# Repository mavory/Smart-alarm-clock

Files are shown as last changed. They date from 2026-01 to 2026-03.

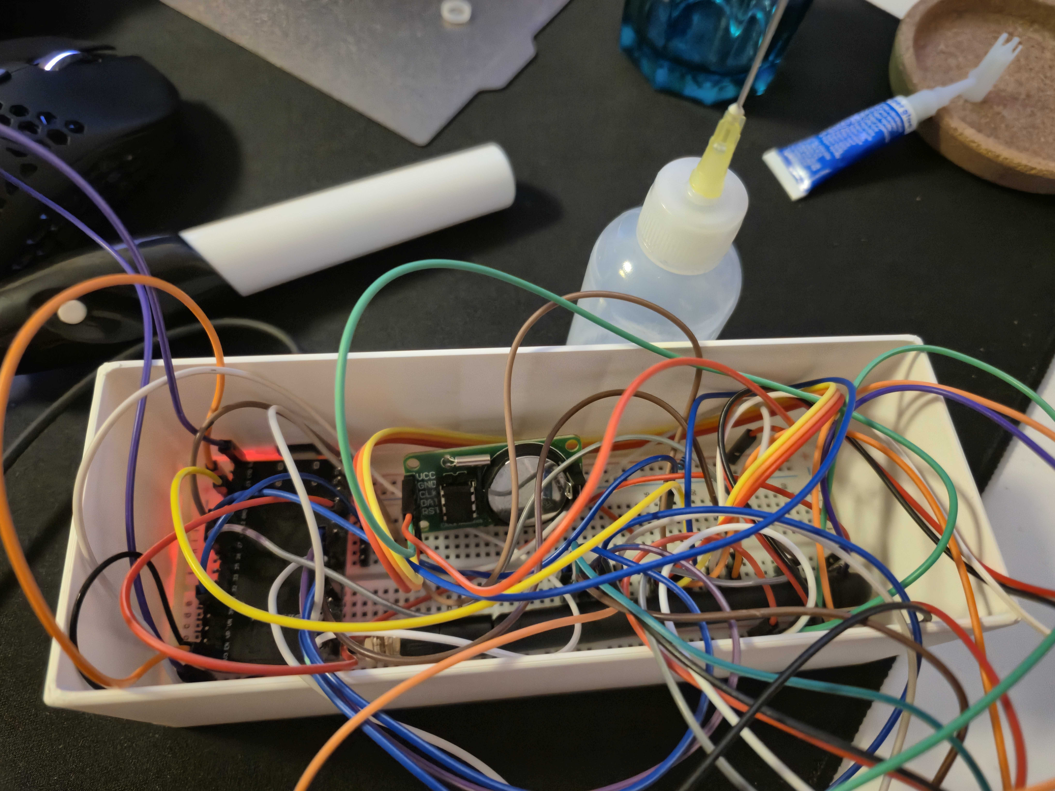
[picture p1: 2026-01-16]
Photos/20260116_223351.jpg

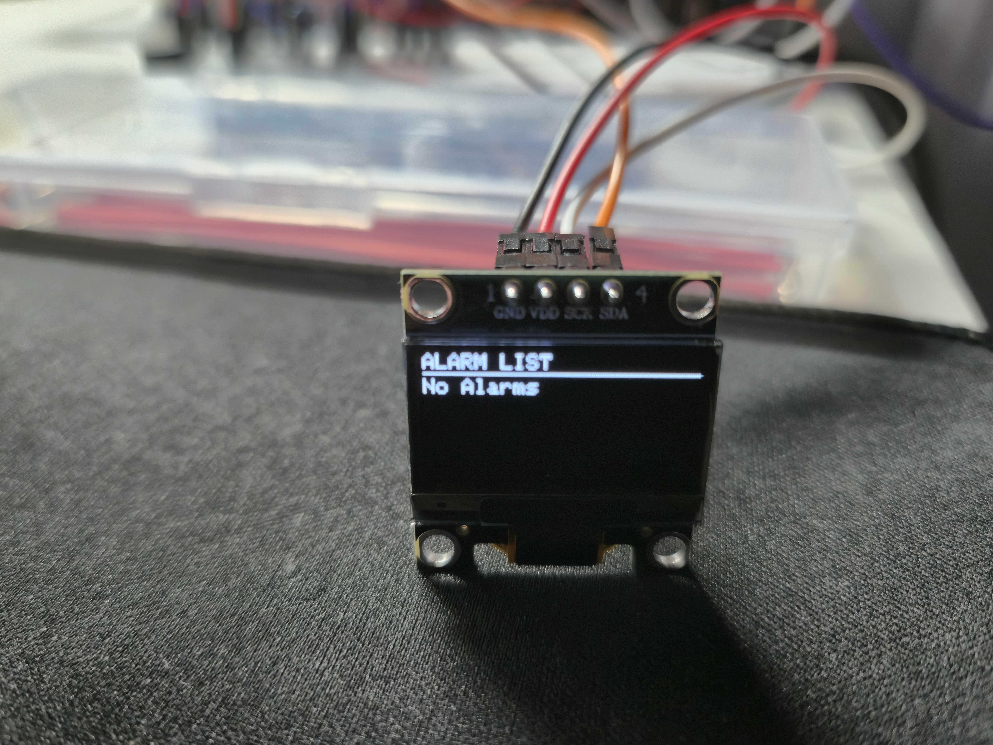
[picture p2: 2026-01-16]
Photos/20260112_203040.jpg

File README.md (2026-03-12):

# Smart Alarm Clock (SAC)

Using ESP32 you can have your own alarm clock that is controllable via the web!

## Why did I do this?

I was always late or needed some encouragement! So I created SAC, which is web-controlled and very compact and minimalist. Now I can adjust my alarm clock via the web on my PC while I'm in the kitchen (for example).

## Features

- Web interface
- You can edit alarms via the web
- You see diagnostics on the display
- Day/night mode

## Scripts

It's the only script you need and it's about 460 lines long! It contains everything from libraries to the website. 
Just edit the WiFi and password on line 237 and you can upload it straight to the ESP32 and everything should work.

### Home page:


## How it works?

On the website you choose what you need, for example, you create a one-day alarm clock with vibration and buzzer for 21:30. At 21:30 your alarm will start and you can turn it off using the button on the website or via the button directly on the alarm clock.
Also, if you press the button twice, you will see all current alarms on the display and if you hold the button, you will get to the diagnostics, where you can see all important information!

### Libraries:

```
- Arduino.h
- WiFi.h
- ESPAsyncWebServer.h 
- AsyncTCP.h
- Adafruit_NeoPixel.h
- LittleFS.h
- SD.h
- SPI.h
- Wire.h
- Adafruit_GFX.h
- Adafruit_SSD1306.h
- RtcDS1302.h
- ThreeWire.h
- OneButton.h
- time.h
```

## 3D models

https://www.tinkercad.com/things/f3PBRpHUPhY-clock?sharecode=p_ixkk5DhO9dDXulNEwirXyC8I3PMVLbobYcKOfEwlo

Here is a view of the top and bottom of the case:





## Wiring Diagram



## BOM (Bill of Materials)

| Item | Quantity | Price | Link |
|---|---|---|---|
| ESP32 | 1 | $5.43 | [Buy](https://www.aliexpress.com/item/1005009694232832.html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) |
| OLED display | 1 | $1.44 | [Buy](https://www.aliexpress.com/item/32896971385.html?spm=a2g0o.order_list.order_list_main.73.59371802jT2w75) |
| SD card module | 1 | $0.56 | [Buy](https://www.aliexpress.com/item/1005009113598175.html?spm=a2g0o.order_list.order_list_main.48.59371802jT2w75) |
| Breadboard | 1 | $2.56 | [Buy](https://www.aliexpress.com/item/1005009799908389.html) |
| Vibration motor | 1 | $0.8 | [Buy](https://www.aliexpress.com/item/1005005518779084.html?spm=a2g0o.order_list.order_list_main.84.59371802jT2w75) |
| Buzzer | 1 | $1.28 | [Buy](https://www.aliexpress.com/item/1005006260328559.html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) |
| Jumpers | Much | $4.73 | [Buy](https://www.aliexpress.com/item/1005002611994443.html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) |
| Button | 1 | $.2.02 | [Buy](https://www.aliexpress.com/item/1005007197228321.html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) |
| RTC modul | 1 | $1.78 | [Buy](https://www.aliexpress.com/item/1005006627321251.html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) |
| Shipping to CZ | / | $3.96 | / |

## There is the final video of how it works!!

_Here is a youtube video where you can see how it works:_ [Link](https://youtu.be/AV3PfRDRrco)



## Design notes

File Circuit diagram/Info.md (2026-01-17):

# Wiring Diagram 

### Inputs:
- **Button:**
  - SIG: GPIO 4
  - VCC: 5V 
  - GND: GND
- **LDR Photosensor:**
  - SIG: GPIO 34
  - Circuit: 3.3V --- LDR --- GPIO 34 --- 10k resistor --- GND

### Outputs:
- **Vibration Motor Module:**
  - SIG: GPIO 26
  - VCC: 5V
  - GND: GND
- **Buzzer Module:**
  - SIG: GPIO 33
  - GND: GND

### Display & Storage:
- **OLED Display:**
  - SDA: GPIO 21
  - SCL: GPIO 22
  - VCC: 5V
  - GND: GND
- **MicroSD Card Module (SPI):**
  - CS: GPIO 5
  - MOSI: GPIO 23
  - MISO: GPIO 19
  - SCK: GPIO 18
  - VCC: 5V
  - GND: GND

### Real Time Clock:
- **RTC DS1302 (3-Wire):**
  - DAT (I/O): GPIO 14
  - CLK (SCLK): GPIO 13
  - RST (CE): GPIO 27
  - VCC: 3.3V
  - GND: GND

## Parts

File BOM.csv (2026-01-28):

Item | Quantity | Price | Link
ESP32 | 1 | $5.43 | https://www.aliexpress.com/item/1005009694232832.html?curPageLogUid=bPYYmnweQOZ8
OLED display | 1 | $1.44 | https://www.aliexpress.com/item/32896971385.html
SD card module | 1 | $0.56 | https://www.aliexpress.com/item/1005009113598175.html
Breadboard | 1 | $2.56 | https://www.aliexpress.com/item/1005009799908389.html
Vibration motor | 1 | $0.8 | https://www.aliexpress.com/item/1005005518779084.html
Buzzer | 1 | $1.28 | https://www.aliexpress.com/item/1005006260328559.html?curPageLogUid=u9zf8d5xh8uM
Jumpers | Much | $4.73 | https://www.aliexpress.com/item/1005002611994443.html?curPageLogUid=fx2zB0EGcu5H
Button | 1 | $.2.02 | https://www.aliexpress.com/item/1005007197228321.html?curPageLogUid=niWf4yREvIVl
RTC modul | 1 | $1.78 | https://www.aliexpress.com/item/1005006627321251.html?curPageLogUid=19tjyUq9NzO2
Shipping to CZ | / | $3.96 | /

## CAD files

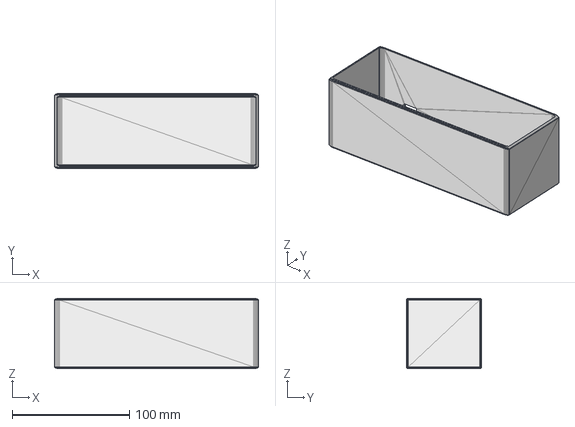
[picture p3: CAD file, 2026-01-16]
CAD/Bottom.step
174.0 x 64.0 x 60.0 mm

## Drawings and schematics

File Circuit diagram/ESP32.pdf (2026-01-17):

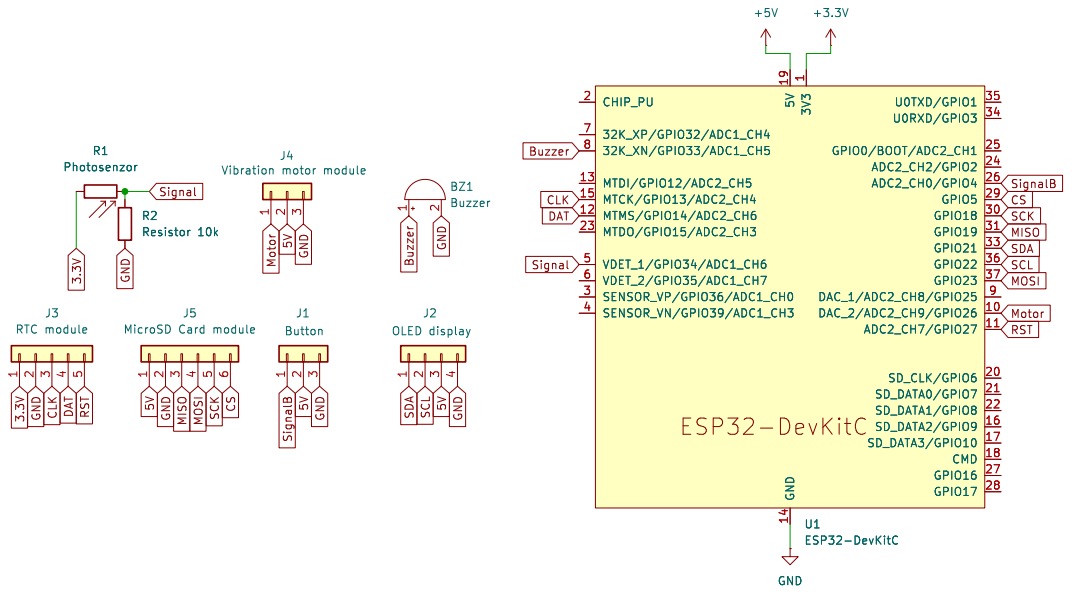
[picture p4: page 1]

1 U0TXD/GPIO1 35 U0RXD/GPIO3 34 GPIO0/BOOT/ADC2_CH1 25 ADC2_CH2/GPIO2 24 ADC2_CH0/GPIO4 26 GPIO5 29 GPIO18 30 GPIO19 31 GPIO21 33 GPIO22 36 GPIO23 37 DAC_1/ADC2_CH8/GPIO25 9 DAC_2/ADC2_CH9/GPIO26 10 ADC2_CH7/GPIO27 11 SD_CLK/GPIO6 20 SD_DATA0/GPIO7 21 SD_DATA1/GPIO8 22 SD_DATA2/GPIO9 16 SD_DATA3/GPIO10 17 CMD 18 GPIO16 27 GPIO17 28 U1ESP32-DevKitC GND

Id: 1/1 Title: Smart Alarm Clock (SAC) File: ESP32.kicad_sch Sheet: /

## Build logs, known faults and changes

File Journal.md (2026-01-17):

<!--
  This journal is auto generated by Hack Club Blueprint.
-->

## 1/10/2026 12 PM - The beginning of my project!!  

_Time spent: 1.2h_  

I was thinking about what to create and suddenly it occurred to me that I could create a **SMART ALARM CLOCK**! It would have: 
- ESP32
- RTC Module
- OLED display (128x64)
- Passive buzzer
- Photosensor
- Vibration motor
- Button
- MicroSD card adapter
- Speaker

**Everything would work via the web**, where sounds could be recorded, e.g. **buzzer**, **vib. motor** and so on could be turned off. 
Also, the clock would always connect to WiFi at **3:00 local time** and adjust the time!

  

## 1/10/2026 10:40 PM - Connecting the components :)  

_Time spent: 0.9h_  

At first I was wondering if I should use a **smaller breadboard** or a **bigger one. I decided to go for the bigger one so that I wouldn't get lost later.**
First I started connecting the cables to the components and later I connected them to the breadboard, unfortunately I don't have **female to female**, so I had to use the _2x more cables method again_... 



## 1/10/2026 10:46 PM - Component testing!  

_Time spent: 0.7h_  

When I had it connected, I started testing each thing **one by one on short codes**, because I hadn't worked with a few things yet. **At first**, the display didn't work, so I wondered why...
After a while, I found out that it was the code, so I was relieved and I thought about whether I should still use the **breadboard power supply**, but I decided not to use it. When I had everything ready and tested, I moved on to soldering.

Snímek obrazovky 2026-01-10 224529

## 1/10/2026 10:52 PM - Soldering   

_Time spent: 1.4h_  

Since I had just bought **an amplifier and a speaker**, I had to connect them somehow first. I thought I would do it easily - I would use a pin strip, but it wasn't that easy. **The holes were too close together**, so I thought I could put it in a **breadboard** and it wasn't...
So I decided to solder it with wires. I first prepared the wires for powering the amplifier itself and when I had them, **I also soldered the speaker**.



## 1/10/2026 11:07 PM - Start of coding  

_Time spent: 1.2h_  

After **successful soldering**, I quickly moved on to writing the code. I had never written any code before and I was wondering **how I would make the speaker work** and everything together.
At first, I came up with the code when I would not use the speaker yet and later I would put it there. I was more confused about the **functionality of the MicroSD card** module, which always blubbed 💀 - today too... When I uploaded the code, writing to the card did not work for me and I also did not know why, **the website did not work.**


## 1/10/2026 11:36 PM - MicroSD card works!  

_Time spent: 0.7h_  

When my **SD card** didn't work, I decided to put it in my computer again and suddenly it showed nothing, I formatted the card, I don't know why... So I put it on **FAT32** so that the ESP32 could read it and upload the files important for the next code there.
I started to redo the **errors** in my code that had been bothering me so far and I made a function to always tell me if the SD card was fine.
I connected everything and it worked, the **website didn't look very nice**, but I didn't bother with that yet, because I knew that more important things were waiting for me.



## 1/10/2026 11:53 PM - Continuing coding  

_Time spent: 1.2h_  

I thought everything would go quickly, but as soon as **I started coding**, I was looking for a library that would be good for Bluetooth, I couldn't find the one I wanted, but after some time I found it: _BluetoothA2DPSink.h_. 
It worked well and I was able to connect my phone to the **ESP32**, but I had one big problem... The antenna can only handle **Bluetooth or WiFi**, so I came up with a brilliant solution that when Bluetooth is turned on, WiFi stays in "standby mode" and waits. 
**Everything worked** and I was able to connect the speaker later.


## 1/11/2026 11 AM - ONE BIG MISTAKE  

_Time spent: 2.1h_  

When I had the code ready, I could move on to connecting the **Speaker to the ESP32**, I added another **10uF** capacitor there to cover the noise, I also connected a **100uF** to the power supply... So when I changed the code and uploaded it to the **ESP32**, unfortunately it didn't work at first, I don't know why, it just made noise.
I tried editing the code, **playing music** only on the bits that the ESP32 reads,.. and nothing. So I spent a lot of time just testing if it works and probably doesn't work. So **I removed it** from the whole project.



## 1/11/2026 4 PM - Rewriting the code but without the speaker  

_Time spent: 1.5h_  

When I recovered from everything, I started to redo the code so that it **would work** even without a speaker. **I redid all the pins** to make it as easy as possible and started coding. I had to start all over again...
The **website was completely redesigned** into a space theme, but I might change it. I was more bothered by the fact that the _ArduinoJSON_ library didn't work for me, so after about an hour **I immediately put it away** and continued without it.



## 1/12/2026 7 PM - Web interface  

_Time spent: 2.1h_  

After a few hours I finished the **web interface**. I completely redesigned it because it looked like **space** at first and wasn't black and white - **Now it's modern** and minimalist with elements and buttons to control the **alarm clock**!

### Here is an older version:


### Here is the new modern version!!


**In the new version there are:**
- buttons for testing the vibration motor, turning off the OLED, adding a new alarm (you can choose if you want a buzzer or a vibration motor)
- I can also see how much space is left on the SD card
- I can see the temperature of the ESP32  

## 1/12/2026 8 PM - The code is done!!   

_Time spent: 1.3h_  

After the website was finished, sjem started to redo the code to make it modern and have all the features!

### Home screen:
- You can see the date
- You can see the exact time
- Signaling if you are connected to WiFi
- Day mode or night mode


### Diagnostics:
- IP address
- RAM
- How long the system has been running
- How many times has the alarm been set


### Alarm page:
- You can see all your set alarms


## 1/16/2026 6 PM - Making a 3D case!!  

_Time spent: 0.9h_  

After **finishing the code**, I started working on the **3D case**, which is very important to print well. I do everything in **Tinkercad**, because I find it to be the lightest and _free program_ running on the web, so **I liked it** a while ago.
At first, I started making the bottom part, which has dimensions of **174x64** (_the walls have a size of +- **2mm**_). When I had the bottom part, I later moved to the **top part**, which will be heavier, mainly because of the **components that will be there**.

### Bottom part:



## 1/16/2026 7:29 PM - Printing and measuring  

_Time spent: 0.6h_  

In the meantime, I started measuring **all the components** that I would place on the top.
I started with the **OLED display** and gradually continued with the **photosensor**, **button**,....
The hardest part was probably **figuring out the right dimensions** for the displays so that everything **would fit and work**.



## 1/16/2026 7:45 PM - Making a top cover for a 3D case  

_Time spent: 1.1h_  

Right after **measuring**, sjem moved back to TinkerCad and continued **modeling the top cover**, which was important to make as accurate as possible.
I placed holes on the top for the **OLED**, **buzzer**, **photosensor**, and **button**.
Everything has a little gap, so everything should fit well!
(_I also created a **3D model** of the button that will be glued to the switch_)

### Overall view of the 3D model:


### Top view:

_Hopefully everything will work out and I will be able to move on!_  

## 1/16/2026 9 PM - Code editing!  

_Time spent: 0.7h_  

While I was waiting for the upper part of the **3D case**, I decided to finish the code to make it more stable.
I also **edited the labels** to make it a little easier to understand. Before, the photosensor didn't work very well for me, sometimes after a reset the **ESP32** worked and sometimes it took a break... So I rewrote some more and it works _beautifully_!


## 1/16/2026 10:36 PM - Cosmetic treatment for 3D case  

_Time spent: 0.5h_  

After printing everything, I prepared things for gluing, editing, etc. **3D case**.
**At the beginning**, I also prepared a buzzer and a photosensor to connect to the jumpers so that they could be inserted into the case! I also **adjusted the cables** so that everything fit well and something didn't fall out right away...
Next, I took a knife and **cut off the edges** that were sticking out and generally sanded the surface of the 3D case a little!


## 1/16/2026 10:48 PM - Placing things in the top of the 3D case  

_Time spent: 1.5h_  

When I **finished the cosmetic adjustments**, I moved on to putting things in the top of the **3D case**!
- First I started with the **buzzer**, which held there beautifully and didn't need glue.
- Then I added a button that needed a **very small amount of glue** so that it wouldn't fall off when I pressed it...
- I also put a **photosensor** in the hole, but that one went worse - the hole was about 1mm too small (_even though I measured it correctly, so there's still a gap there_), but then I put it in there and connected the wires.
- Last I put the **OLED in the top**, which I didn't want to glue, so I decided to stick it with **electrical tape** and everything worked beautifully!

_So when I had everything ready, I had to wait for a while for **everything to dry** and in the meantime I did a few things in **KiCad** (but that's a later topic)_

20260116_224936 (1)

## 1/16/2026 11 PM - The case is finally closed!  

_Time spent: 1.2h_  

After a long time, **I finally finished the case**!
Everything works very well and so sjem decided to **glue the upper part** to the lower one - but it wasn't that easy.
First I had to bend the cables to the **photosensor and buzzer** so that the jumpers wouldn't fall out, and even then it happened a few times, so it took me a while.
I also had to rewire the buzzer on the **breadboard** a little, but everything else is great! When I had it, **I finished the last things** and closed it (_I just stretched it with tape to test it..._)
Everything worked, but suddenly the **buzzer didn't work** on the second try, so **I wondered why**, but when **I opened the case**, a wire just fell out, so I said, goooood.
So when I made the **4th try**, everything worked beautifully and I was happy. So I closed the case with glue and could continue with the **circuit diagram**!!

### Cable connection:


### Closed case:


## 1/17/2026 3:28 PM - Circuit diagram  

_Time spent: 1.5h_  

When I finished the overall wiring and the **3D case**, I started making a circuit diagram in KiCad.
It took me quite a while because I had been doing it for a long time, but then **I remembered** how to **do some things**.
I gradually added various devices and connected them to the **ESP32**. The photosensor was probably the most difficult for me because I couldn't find the exact module for it, but after some time I found it. Later I added a **10K resistor** to it and slowly everything was done.


## 1/17/2026 3:38 PM - Circuit diagram is finished!  

_Time spent: 0.8h_  

So when I had everything ready, I started connecting things to the **ESP32**.
At first **I had to look at the code** because I couldn't remember the pins where the **components** were connected, but as I got closer to the end, I started to remember...
After about **0.8 hours** I had everything finished and I rendered it all and **uploaded it** straight to **GitHub**!
Snímek obrazovky 2026-01-17 152935
_Here is the link to download the PDF:_ [ESP32](/user-attachments/blobs/proxy/eyJfcmFpbHMiOnsiZGF0YSI6ODQ0MjEsInB1ciI6ImJsb2JfaWQifX0=--f22b4212b44062768d9ba6f794fccc316fd4df73/ESP32.pdf)  

## 1/17/2026 4 PM - GitHub editing  

_Time spent: 1.3h_  

When I was done, I started editing the **GitHub repo**. I exported everything one by one and later **uploaded everything** to the aforementioned repo.
It took me about half an hour in total, because I always have to convert **.STL** to **.STEP** and also always find out where **my schematic** is saved...

Later, I started writing **README.md**, **Journal.md**, **Info.md**... That probably took me the most time, because it was quite difficult and then I had to edit it a f**ew times anyway**. When I had it, I saved everything **and made a video** of how everything works.


## 1/17/2026 5 PM - SMART ALARM CLOCK IS DONE!!  

_Time spent: 1.8h_  

Using ESP32 you can have your own alarm clock that is controllable via the web!

## Why did I do this?

I was always late or needed some encouragement! So I created SAC, which is web-controlled and very compact and minimalist. Now I can adjust my alarm clock via the web on my PC while I'm in the kitchen (for example).

## Features

- Web interface
- You can edit alarms via the web
- You see diagnostics on the display
- Day/night mode

## Scripts

It's the only script you need and it's about 460 lines long! It contains everything from libraries to the website. 
Just edit the WiFi and password on line 237 and you can upload it straight to the ESP32 and everything should work.

### Home page:


## How it works?

On the website you choose what you need, for example, you create a one-day alarm clock with vibration and buzzer for 21:30. At 21:30 your alarm will start and you can turn it off using the button on the website or via the button directly on the alarm clock.
Also, if you press the button twice, you will see all current alarms on the display and if you hold the button, you will get to the diagnostics, where you can see all important information!

### Libraries:

```
- Arduino.h
- WiFi.h
- ESPAsyncWebServer.h 
- AsyncTCP.h
- Adafruit_NeoPixel.h
- LittleFS.h
- SD.h
- SPI.h
- Wire.h
- Adafruit_GFX.h
- Adafruit_SSD1306.h
- RtcDS1302.h
- ThreeWire.h
- OneButton.h
- time.h
```

## 3D models

Here is a view of the top and bottom of the case:





## Wiring Diagram



## There is the final video of how it works!!

_Here is a youtube video where you can see how it works:_ [Link](https://youtu.be/AV3PfRDRrco)



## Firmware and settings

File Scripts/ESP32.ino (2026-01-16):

#include <WiFi.h>
#include <ESPAsyncWebServer.h>
#include <SD.h>
#include <SPI.h>
#include <Wire.h>
#include <Adafruit_GFX.h>
#include <Adafruit_SSD1306.h>
#include <RtcDS1302.h>
#include <ThreeWire.h>
#include <OneButton.h>
#include "time.h"

//PINOUT
#define PIN_SD_CS    5
#define PIN_BUZZER   33
#define PIN_VIBRO    26   //zde je ten pin pro motor
#define PIN_BTN      4
#define PIN_LDR      34
#define OLED_SDA     21
#define OLED_SCL     22

ThreeWire myWire(14, 13, 27); // DAT, CLK, RST!!!!!
RtcDS1302<ThreeWire> Rtc(myWire);
Adafruit_SSD1306 display(128, 64, &Wire, -1);
AsyncWebServer server(80);
OneButton button(PIN_BTN, true);

bool isAlarmActive = false;
bool oledPower = true;
String globalIP = "0.0.0.0";
unsigned long lastUpdate = 0;
unsigned long stateTimer = 0;
unsigned long bootTime = 0;

enum State { CLOCK, LIST, DIAG };
State displayState = CLOCK;

// Alarm settingues
int actBuzzer = 1;
int actVibro = 1;
int actFreq = 1500;

const char* ntpServer = "pool.ntp.org";
const long  gmtOffset_sec = 3600;     //pro mě to ej gmt+1
const int   daylightOffset_sec = 3600; // letní čas

// esp32 čip teplota
#ifdef __cplusplus
extern "C" { uint8_t temprature_sens_read(); }
#endif

// logika tlacitka
void handleClick() {
  if (isAlarmActive) {
    // stop alarmu
    isAlarmActive = false;
    noTone(PIN_BUZZER);
    digitalWrite(PIN_VIBRO, LOW);
  } else {
    if (!oledPower) {
      oledPower = true;
    } else {
      displayState = CLOCK;
    }
  }
}

void handleDoubleClick() {
  if(!isAlarmActive) { displayState = LIST; stateTimer = millis(); }
}

void handleLongPress() {
  if(!isAlarmActive) { displayState = DIAG; stateTimer = millis(); }
}

void runVibrationEffect() {
  unsigned long m = millis();
  if (actVibro == 1) { 
    // konstanta
    digitalWrite(PIN_VIBRO, HIGH); 
  } 
  else if (actVibro == 2) { 
    int p = m % 1000;
    if ((p > 0 && p < 150) || (p > 250 && p < 400)) digitalWrite(PIN_VIBRO, HIGH);
    else digitalWrite(PIN_VIBRO, LOW);
  }
}

// web, jako vzdy hrozne
const char index_html[] PROGMEM = R"rawliteral(
<!DOCTYPE html>
<html lang="en">
<head>
<meta charset="UTF-8">
<meta name="viewport" content="width=device-width, initial-scale=1">
<title>VORY OS V5</title>
<style>
  :root { --bg: #ffffff; --text: #000000; --acc: #000000; }
  body { background: var(--bg); color: var(--text); font-family: -apple-system, BlinkMacSystemFont, "Segoe UI", Roboto, sans-serif; margin: 0; padding: 20px; max-width: 600px; margin: auto; }
  h1 { border-bottom: 4px solid var(--text); padding-bottom: 10px; letter-spacing: -1px; text-transform: uppercase; }
  .card { border: 2px solid #eee; padding: 20px; border-radius: 12px; margin-bottom: 20px; box-shadow: 0 4px 10px rgba(0,0,0,0.05); }
  label { font-size: 10px; font-weight: 800; text-transform: uppercase; color: #888; display: block; margin-bottom: 8px; }
  .grid { display: grid; grid-template-columns: 1fr 1fr; gap: 15px; }
  input, select, button { width: 100%; box-sizing: border-box; padding: 12px; border: 2px solid #ddd; border-radius: 8px; font-size: 14px; font-weight: 600; background: #fff; appearance: none; }
  input:focus, select:focus { border-color: #000; outline: none; }
  button { background: #000; color: #fff; border-color: #000; cursor: pointer; transition: 0.2s; }
  button:hover { background: #333; transform: translateY(-2px); }
  button.danger { background: #ff3b30; border-color: #ff3b30; }
  button.danger:hover { background: #d63026; }
  .alarm-item { display: flex; justify-content: space-between; align-items: center; padding: 15px 0; border-bottom: 1px solid #eee; }
  .tag { font-size: 10px; background: #eee; padding: 4px 8px; border-radius: 4px; margin-left: 5px; }
  #status-dot { height: 10px; width: 10px; background-color: #ccc; border-radius: 50%; display: inline-block; margin-right: 5px; }
  .online { background-color: #34c759 !important; }
</style>
<script>
  function el(id){ return document.getElementById(id); }
  function toggleDate(v){ el('date_box').style.display = (v==='once') ? 'block' : 'none'; }
  
  function loadData() {
    fetch('/api/list').then(r=>r.text()).then(h => el('alarm-list').innerHTML = h);
    fetch('/api/status').then(r=>r.json()).then(j => {
      el('sys-status').innerText = j.status;
      el('sys-temp').innerText = j.temp + "°C";
      el('sd-usage').innerText = j.sd;
      el('status-dot').className = (j.online ? 'online' : '');
    });
  }
  
  function sendCmd(cmd) { fetch('/cmd?do='+cmd).then(()=>loadData()); }
  
  function addAlarm() {
    let t = el('t').value, m = el('m').value;
    let d = (m === 'daily') ? 'daily' : el('d_val').value;
    let b = el('b').value, v = el('v').value, f = el('f').value;
    if(!t) return alert("Please set time!");
    
    fetch(`/api/add?t=${t}&d=${d}&b=${b}&v=${v}&f=${f}`).then(() => {
      el('t').value = '';
      loadData();
    });
  }
  
  function delAlarm(id) {
    if(confirm("Delete this alarm?")) {
      fetch(`/api/del?id=${id}`).then(()=>loadData());
    }
  }

  setInterval(loadData, 2000);
</script>
</head>
<body onload="loadData()">
  <h1>VORY OS <span style="font-size:12px; vertical-align:middle; background:#000; color:#fff; padding:2px 6px; border-radius:4px;">PRO</span></h1>
  
  <div class="card">
    <div style="display:flex; justify-content:space-between;">
      <div><span id="status-dot"></span><span id="sys-status">LOADING...</span></div>
      <div id="sys-temp">--°C</div>
    </div>
    <div style="margin-top:10px; font-size:12px; color:#666;">SD Storage: <span id="sd-usage">--</span></div>
  </div>

  <div class="card">
    <label>Control Center</label>
    <div class="grid">
      <button onclick="sendCmd('oled')">Toggle OLED</button>
      <button onclick="sendCmd('ntp')">NTP Sync (Net)</button>
      <button onclick="sendCmd('test_vib')">Test Motor</button>
      <button class="danger" onclick="sendCmd('kill')">STOP ALARM</button>
    </div>
  </div>

  <div class="card">
    <label>New Alarm</label>
    <div class="grid">
      <input type="time" id="t">
      <select id="m" onchange="toggleDate(this.value)">
        <option value="daily">Repeat Daily</option>
        <option value="once">One-time (Date)</option>
      </select>
    </div>
    <div id="date_box" style="display:none; margin-bottom:10px;">
      <input type="date" id="d_val">
    </div>
    <div class="grid">
      <select id="b"><option value="1">Buzzer: Loud</option><option value="2">Buzzer: Pulse</option><option value="0">Silent</option></select>
      <select id="v"><option value="1">Vibro: Constant</option><option value="2">Vibro: Heartbeat</option><option value="0">Off</option></select>
    </div>
    <input type="number" id="f" value="1500" placeholder="Hz (Pitch)">
    <button onclick="addAlarm()" style="margin-top:10px;">SAVE ALARM</button>
  </div>

  <div class="card">
    <label>Active Alarms</label>
    <div id="alarm-list">Loading...</div>
  </div>
</body>
</html>
)rawliteral";

// seťup
void setup() {
  Serial.begin(115200);
  bootTime = millis();
  
  pinMode(PIN_VIBRO, OUTPUT);
  pinMode(PIN_BUZZER, OUTPUT);
  pinMode(PIN_LDR, INPUT);
  
  // test motoru
  digitalWrite(PIN_VIBRO, HIGH); delay(200); digitalWrite(PIN_VIBRO, LOW);

  Wire.begin(OLED_SDA, OLED_SCL);
  display.begin(SSD1306_SWITCHCAPVCC, 0x3C);
  
  // booting animacia
  display.clearDisplay();
  display.setTextSize(1); display.setTextColor(WHITE);
  display.setCursor(30, 20); display.println("VORY OS V5");
  display.drawRect(14, 40, 100, 10, WHITE);
  for(int i=0; i<100; i+=10) {
    display.fillRect(16, 42, i, 6, WHITE);
    display.display();
    delay(50);
  }

  button.setClickTicks(200);
  button.setPressTicks(2000);
  button.attachClick(handleClick);
  button.attachDoubleClick(handleDoubleClick);
  button.attachLongPressStart(handleLongPress);

  Rtc.Begin();
  if (!SD.begin(PIN_SD_CS)) { Serial.println("SD Fail"); }

  // WiFi
  WiFi.begin("Vory", "Pazout2604"); // CHANGE PASSWORD
  int attempt = 0;
  while (WiFi.status() != WL_CONNECTED && attempt < 10) { delay(500); attempt++; }
  if(WiFi.status() == WL_CONNECTED) globalIP = WiFi.localIP().toString();
  
  configTime(gmtOffset_sec, daylightOffset_sec, ntpServer);

  server.on("/", HTTP_GET, [](AsyncWebServerRequest *r){ r->send(200, "text/html", index_html); });
  
  server.on("/api/status", HTTP_GET, [](AsyncWebServerRequest *r){
    String json = "{";
    json += "\"status\":\"" + String(isAlarmActive ? "ALARM ACTIVE" : "SYSTEM READY") + "\",";
    json += "\"temp\":\"" + String((temprature_sens_read() - 32) / 1.8, 1) + "\",";
    json += "\"online\":" + String(WiFi.status() == WL_CONNECTED ? "true" : "false") + ",";
    json += "\"sd\":\"" + String(SD.totalBytes() / (1024*1024)) + " MB\"";
    json += "}";
    r->send(200, "application/json", json);
  });

  server.on("/cmd", HTTP_GET, [](AsyncWebServerRequest *r){
    String cmd = r->getParam("do")->value();
    if(cmd == "oled") oledPower = !oledPower;
    else if(cmd == "kill") { isAlarmActive = false; noTone(PIN_BUZZER); digitalWrite(PIN_VIBRO, LOW); }
    else if(cmd == "test_vib") { 
      digitalWrite(PIN_VIBRO, HIGH); delay(1000); digitalWrite(PIN_VIBRO, LOW); 
    }
    else if(cmd == "ntp") {
      struct tm timeinfo;
      if(getLocalTime(&timeinfo)){
        RtcDateTime now(timeinfo.tm_year + 1900, timeinfo.tm_mon + 1, timeinfo.tm_mday, timeinfo.tm_hour, timeinfo.tm_min, timeinfo.tm_sec);
        Rtc.SetDateTime(now);
      }
    }
    r->send(200);
  });

  server.on("/api/list", HTTP_GET, [](AsyncWebServerRequest *r){
    File f = SD.open("/alarms.txt", FILE_READ);
    String html = ""; int id = 0;
    if(!f){ r->send(200, "text/plain", "SD Error"); return; }
    
    while(f.available()){
      String l = f.readStringUntil('\n');
      if(l.length() > 5) {
        int s1 = l.indexOf('|'); int s2 = l.indexOf('|', s1+1);
        String t = l.substring(0, s1); 
        String d = l.substring(s1+1, s2);
        if(d != "daily") { 
            // Format 2026-01-12 -> 12.01.
            d = d.substring(8,10) + "." + d.substring(5,7) + "."; 
        } else {
            d = "Daily";
        }
        
        html += "<div class='alarm-item'>";
        html += "<div><span style='font-size:18px; font-weight:bold'>" + t + "</span> <span class='tag'>" + d + "</span></div>";
        html += "<button class='danger' style='width:auto; padding:5px 10px; font-size:12px' onclick='delAlarm("+String(id)+")'>DEL</button>";
        html += "</div>";
        id++;
      }
    }
    f.close();
    r->send(200, "text/html", html.length() > 0 ? html : "No Alarms Set");
  });

  server.on("/api/add", HTTP_GET, [](AsyncWebServerRequest *r){
    String row = r->getParam("t")->value() + "|" + r->getParam("d")->value() + "|" + r->getParam("b")->value() + "|" + r->getParam("v")->value() + "|" + r->getParam("f")->value();
    File f = SD.open("/alarms.txt", FILE_APPEND); f.println(row); f.close();
    r->send(200);
  });

  server.on("/api/del", HTTP_GET, [](AsyncWebServerRequest *r){
    int id = r->getParam("id")->value().toInt();
    File f = SD.open("/alarms.txt", FILE_READ);
    String content = ""; int cnt = 0;
    while(f.available()){
      String l = f.readStringUntil('\n');
      if(cnt != id && l.length() > 0) content += l + "\n";
      cnt++;
    }
    f.close();
    SD.remove("/alarms.txt"); // Clean delete
    File fw = SD.open("/alarms.txt", FILE_WRITE);
    fw.print(content);
    fw.close();
    r->send(200);
  });

  server.begin();
}

// loopppp
void loop() {
  button.tick();
  
  if(displayState != CLOCK && millis() - stateTimer > 10000) displayState = CLOCK;

  RtcDateTime now = Rtc.GetDateTime();

  if (now.Second() == 0 && !isAlarmActive) {
    File f = SD.open("/alarms.txt", FILE_READ);
    char curT[6], curD[11];
    sprintf(curT, "%02d:%02d", now.Hour(), now.Minute());
    sprintf(curD, "%04d-%02d-%02d", now.Year(), now.Month(), now.Day());
    
    while(f.available()){
      String l = f.readStringUntil('\n');
      if (l.startsWith(curT)) {
        int s1 = l.indexOf('|'); int s2 = l.indexOf('|', s1+1);
        int s3 = l.indexOf('|', s2+1); int s4 = l.indexOf('|', s3+1);
        
        String d = l.substring(s1+1, s2);
        if (d == "daily" || d == String(curD)) {
          isAlarmActive = true;
          actBuzzer = l.substring(s2+1, s3).toInt();
          actVibro = l.substring(s3+1, s4).toInt();
          actFreq = l.substring(s4+1).toInt();
          break; // trigger
        }
      }
    }
    f.close();
  }

  if (isAlarmActive) {
    unsigned long m = millis();
    
    if (actBuzzer == 1) tone(PIN_BUZZER, actFreq);
    else if (actBuzzer == 2) tone(PIN_BUZZER, (m % 500 < 250) ? actFreq : 0);
    else noTone(PIN_BUZZER);

    runVibrationEffect();
  }

  // oled
  if (millis() - lastUpdate > 200) {
    lastUpdate = millis();
    display.clearDisplay();

    if (!oledPower && !isAlarmActive) {
      display.display(); // OFF
    } 
    else {
      int ldr = analogRead(PIN_LDR);
      bool isNight = (ldr < 800);
      display.ssd1306_command(SSD1306_SETCONTRAST);
      display.ssd1306_command(isNight ? 0x01 : 0xCF); // snížení jasu

      if (isAlarmActive) {
        // ALARM 
        static bool flash = false; flash = !flash;
        if(flash) display.fillRect(0,0,128,64, WHITE);
        display.setTextColor(flash ? BLACK : WHITE);
        display.setTextSize(3); 
        display.setCursor(20, 22); display.print("ALARM");
      } 
      else {
        display.setTextColor(WHITE);
        
        if (displayState == CLOCK) {
          // datum
          display.setTextSize(1);
          char dBuf[20]; 
          sprintf(dBuf, "%02d/%02d/%04d", now.Day(), now.Month(), now.Year());
          display.setCursor(0, 0); display.print(dBuf);
          
          if(WiFi.status() == WL_CONNECTED) {
            display.setCursor(100,0); display.print("WiFi");
          }

          // separator
          display.drawFastHLine(0, 10, 128, WHITE);

          // body
          display.setTextSize(4);
          char tBuf[6]; sprintf(tBuf, "%02d:%02d", now.Hour(), now.Minute());
          
          // velky text
          display.setCursor(5, 18); 
          display.print(tBuf);

          // separator
          display.drawFastHLine(0, 52, 128, WHITE);

          // footer
          display.setTextSize(1);
          display.setCursor(0, 56);
          display.print(isNight ? "MODE: NIGHT" : "MODE: DAY");
        } 
        else if (displayState == LIST) {
          display.setTextSize(1); 
          display.setCursor(0,0); display.println("ALARM LIST");
          display.drawFastHLine(0, 9, 128, WHITE);
          
          File f = SD.open("/alarms.txt", FILE_READ);
          int rowY = 12;
          int count = 0;
          while(f.available() && count < 4) {
            String l = f.readStringUntil('\n');
            int pipe = l.indexOf('|');
            if(pipe > 0) {
              String t = l.substring(0, pipe);
              display.setCursor(0, rowY);
              display.print("> " + t);
              rowY += 10;
              count++;
            }
          }
          f.close();
          if(count==0) { display.setCursor(0,12); display.print("No Alarms"); }
        }
        else if (displayState == DIAG) {
          display.setTextSize(1);
          display.setCursor(0,0); display.println("SYSTEM INFO");
          display.drawFastHLine(0, 9, 128, WHITE);
          display.setCursor(0,12);
          display.print("IP: "); display.println(globalIP);
          display.print("RAM: "); display.print(ESP.getFreeHeap()/1024); display.println(" KB");
          display.print("UP: "); display.print(millis()/60000); display.println(" min");
          display.print("VIB: "); display.println(actVibro);
        }
      }
      display.display();
    }
  }
}

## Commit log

2026-01-12 Circuit diagram
2026-01-16 .STEP files
    [Bottom.step]
2026-01-17 Circuit diagram
    Added detailed wiring diagram with inputs, outputs, display, storage, and RTC connections.
2026-01-17 Journal.md
    Updated the journal with details about the circuit diagram creation process and added images.
2026-01-17 README.md
    Expanded the README to provide detailed information about the Smart Alarm Clock project, including features, scripts, wiring diagrams, libraries used, and a final video demonstration.
2026-01-17 README.md
    Updated README to include new sections on 3D models and wiring diagram, and removed redundant content.
2026-01-28 README.md
    Added a Bill of Materials (BOM) section with item details.
